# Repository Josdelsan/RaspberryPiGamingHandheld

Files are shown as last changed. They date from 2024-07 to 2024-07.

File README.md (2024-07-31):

# Raspberry Pi Gaming Handheld

This repository contains all the information required in order to build a Raspberry Pi Zero (w/w 2) handheld gaming device. This project was done for educational purposes and it is not intended to be sold or distributed. The guides provided covers one or multiple solutions for each part of the device (Display, Power, Audio, Controls, etc.), the user is free to choose the one that fits their needs better. If you have any issues or you want to showcase your build, feel free to open an issue.

This project was especially designed for fitting a Raspberry Pi Zero inside a GameBoy Advance shell. The GameBoy Advance/GameBoy Color are great options for this project because they are cheap and easy to find. You can adapt the project to fit any other form factor you want.

gba_v1_tloz_2
*GBA based Raspberry Pi Zero 2 W handheld front view*

## Disclaimer

This project requires soldering skills and comprehensive knowledge abour RPI software and hardware. It is not recommended for beginners. Even if the parts cost are low, it may be more expensive than just buying an emulator handheld device like the [Miyoo Mini Plus](https://www.miyoogame.com/product/miyoo-mini-plus-retro-handheld-game-console/) or the [Anbernic RG35XXSP](https://anbernic.com/products/rg35xxsp).

When emulating games, please make sure you own the original copy of the game. This project does not provide any ROMs or information on how to obtain them. All the trademarks and copyrights are property of their respective owners.

## Photos

gba_v1_top
*GBA based Raspberry Pi Zero 2 W handheld top view*

gba_v1_open_back
*GBA based Raspberry Pi Zero 2 W handheld removed back shell*

gba_v1_open_2
*GBA based Raspberry Pi Zero 2 W handheld disassembled*

gba_v0_on
*First iteration of GBA based Raspberry Pi Zero W handheld gaming deviced without shell*

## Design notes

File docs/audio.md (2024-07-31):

# Audio

Audio is an important part of the gaming experience. In this section we will cover an audio solution for the Raspberry Pi Zero W. This solution is based on the I2S capabilities of the Raspberry Pi Zero. You can check the Raspberry Pi PCM pins [here](https://pinout.xyz/pinout/pcm).

**IMPORTANT**, this solution is not currently working for the Raspberry Pi Zero W 2, I am looking for a solution since it works perfectly for the Raspberry Pi Zero W.

## MAX98357A

The MAX98357A is a small I2S amplifier that can be used to output audio from the Raspberry Pi Zero. Adafruit sells it for a few dollars and has an [amazing tutorial](https://learn.adafruit.com/adafruit-max98357-i2s-class-d-mono-amp/raspberry-pi-wiring) on how to use it (wiring and software configuration). The full documentation of Adafruit MAX98357A can be found [here](https://cdn-learn.adafruit.com/downloads/pdf/adafruit-max98357-i2s-class-d-mono-amp.pdf). You can check in the documentation the supported speakers.

If the `dtoverlay=max98357a` provided by Adafruit is not working for you, you can try the following configuration:

```bash
dtoverlay=hifiberry-dac
dtoverlay=i2s-mmap
```

## Dealing with `VolumeControl::init() - Failed to find mixer elements` error

If you have RetroPie installed in your Raspberry Pi Zero, you might encounter the following error when booting games:

```bash
VolumeControl::init() - Failed to find mixer elements
```

This error will affect Raspberry Pi Zero W 2 users that tried to configure the audio and commented out the `dtparam=audio=on` line in the `/boot/config.txt` file. If you try to change audio configurations in the `raspi-config` tool, you will get the error that there is no audio device detected. This error does not affect gameplay, you can play without audio.

If you are going to play without audio, uncomment the `dtparam=audio=on` line in the `/boot/config.txt` file and select HDMI as the audio output in the `raspi-config` tool. This will likely fix the error and you will be able to play without audio. This [post in RetroPie](https://retropie.org.uk/forum/topic/26628/audio-issues-after-latest-raspbian-updates-june-2020) forum goes deeper into this issue.

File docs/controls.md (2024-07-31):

# Controls

## Hardware

For creating a gaming handheld device and avoid using an external controller, we need to add some buttons to the Raspberry Pi. Using internal pull-up/pull-down resistors, we can connect switch buttons directly to the GPIO pins of the Raspberry Pi. Check the Raspberry Pi Zero pinout [here](https://pinout.xyz/).

The tricky part is to add buttons in a way it fits the case you are using and it is comfortable to play. In this section we will cover a few options for adding buttons to the Raspberry Pi Zero. Some of the options are more complex and professional (custom PCBs) and others are more simple and DIY (protoboard).

### Buying a DIY Button PCB Board

One of the easiest and cheapest ways to add buttons to the project is to buy a DIY button PCB board for your specific case. They can be easily found on websites like AliExpress or eBay for the GBA/GB/GBC cases. This PCB will perfectly fit the case (screw holes, case holes, PCB thickness) and will be compatible with the original conductive silicone rubber pads that usually come with the case.



*DIY PCB bought online*

They are not very well documented. You will need to use a multimeter to check which pins are conected to each button and ground. You can directly solder each button to the Raspberry Pi GPIO pins and ground to any GND pin. Sometimes they will include a footprint for a resistor and a smd LED (power LED) that you can omit. This option will give you the most professional look and feel while keeping the cost low.

### DIY Protoboard

If you have some protoboards laying around and you are confident about your soldering/cutting skills, you can create your own DIY button board out of it. This options gives you the flexibility of adding more buttons, changing the layout or using different kind of buttons apart from the conductive silicone rubber pads.

You can use the original conductive silicone rubber pads by creating traces using conductive paint, copper tape or applying solder to the protoboard. In replacement of the conductive silicone rubber pads, you can use push buttons, theses are harder to fit inside the case due to their size and height. Becareful about the protoboard thickness, it might not fit the case.

This method requires more time and effort. It is recommended for people that are looking for the ultimate DIY experience. Please, make sure you have the right tools and knowledge before using cutting tools, soldering irons and other dangerous tools.

### Custom PCB

If you are looking for a professional look and feel, you can design your own custom PCB to fit not only the control but also all the other components of the project (more covered in the custom pcb section). This method can be expensive due to manufacturing, shipping and customs inspection costs (depending on your country). If you are already familiar with PCB design, there is not much to say here. This project PCB design was done using KiCad 8.0.

If you are planning to use push or smd buttons, you will need to look for the footprint or design it using the datasheet of the button. Creating the footprint for the conductive silicone rubber pads is easy. I recommend using a photo at 1:1 of the original gaming console PCB for reference. In this project particular case, the buttons footprint was designed to be compatible with the original conductive silicone rubber pads and also some specific smd buttons.



*Custom PCB version 0.1 made for the GBA based handheld (front)*



*Custom PCB version 0.1 made for the GBA based handheld (back)*

### Different Button Types talk

Choosing the right button type is a very personal decision. Some people stick to the silicone rubber feel (GBA/GB/GBC) while others prefer a more mechanical/clikey feel (GBA sp). After using many different form factor button, here are my thoughts and recommendations:

- **Conductive Silicone Rubber Pads**: They are heavily dependent on the preassure you apply between the board and the shell, it might affect the button feel and response. If you have detection issues you can try sticking small cutouts of copper tape to the pads to increase thickness and conductivity. They will fit perfectly inside its case and plastic buttons, they are silent and cheap.
- **Push Buttons**: They have a more consistent feel and response. Becareful with the operating force, you might feel uncomfortable playing games that requires fast button presses. They are really difficult to fit inside the case due to their size and can be noisy. The case plastic buttons might not fit the push buttons, you will need to 3D print custom ones or modify the existing ones (cutting, sanding, adding silicone glue).
- **SMD Buttons**: They will likely require a custom PCB. Due to its size, you can still use the silicone rubber pads to fit the plastic buttons while using the smd buttons underneath. I heavily recommend looking for really low operating force buttons (like the ones used in the GBA SP) to avoid fatigue while playing.



*Different buttons that are viable*



*Rubber silicone pads*

### [Tutorial] Connecting a Button to the Raspberry Pi

In this tutorial we will connect a simple push button to the Raspberry Pi GPIO pins. This is the most basic way to add buttons to the Raspberry Pi. You can use this tutorial as a base for more complex button configurations.

Button will have two ends, one will be connected to the GPIO pin and the other to the GND pin. When the button is pressed, the GPIO pin will be connected to the GND pin and the Raspberry Pi will detect it as a button press.

If you want to check if the button was correctly connected, you can use `gpiozero` python library. In [its documentation](https://gpiozero.readthedocs.io/en/stable/recipes.html#button) you can find a lot of examples with images and code.

## Software

Buttons can be configured using the `gpiozero` python library. This library provides a simple interface for controlling GPIO devices connected to a Raspberry Pi. This allows creating custom buttons shortcuts for specific actions like system shutdown, etc.

In this particular project, since we are using RetroPie, we will use a Python based GPIO Controller called GPIOnext. It provides a CLI for configuring a gamepad using GPIO pins. You can find more information about it in the [GPIOnext official repository](https://github.com/mholgatem/GPIOnext). This is the easiest way to configure a gamepad in RetroPie using GPIO pins.

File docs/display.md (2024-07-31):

# Display

## Hardware options

There are many display options available for RPI. In this project it was chosen to use an SPI TFT LCD display that uses the ILI9341 driver (not ILI9341V). When using a GameBoy Advance shell, both 2.8 and 3.2 inches will fit. The 3.2 inch may require some modifications to the plastic cover that hold the leds under the screen and aditional software configuration in order to adjust screen borders. These screen usually works at a resolution of 320x240 pixels. They are sold in different formats: presoldered to a pcb, 18 pins connector or 40 pins connector.



*ILI9341 displays (red pcb and 18p) and ILI9341V display (black pcb)*

### ILI9341 display presoldered to a pcb

When searching for ILI9341 display online, it is common to find these displays already soldered to a breakout board. This option is the most soldering friendly and easiest to debug but it may not fit inside the desired shell. When looking for a good fitting display, make sure the display is as centered as possible (display ribbon cable in the opposite side of the pins).



*Displays that are sold with a breakout board*

For this project, touch screen is not used. When buying a display, look for displays that do not have exposed touch screen pins, this will save you space (same for sd card slots). You could ultimately remove the pins if you are not going to use them and/or modify the pcb using a cutting tool. Be extremely careful when modifying any pcb since it is very easy to damage the display and make it unusable (**NOT RECOMMENDED**).

When using theses displays, make sure to check the voltage required to power. They usually work at 3.3V or 5V. They are packed with different pins configurations, it is important to check the pins for later driver software configuration. Some manufacturers will replace SDI (MISO) and SDO (MOSI) for a single SDA that works as SDI. For this purpose, only SDI is used.

### ILI9341 18 pins connector display

ILI9341 with 18 pins ribbon connector are usually cheaper than the presoldered displays and easier to fit inside the shell. The downside is that they require precise soldering skills and some kind of breakout board in order to connect it to the RPI. A custom pcb is presented in the custom pcb section for this purpose.



*18 pin connector ILI9341 display*

The 18 pins connector are configured as follows (make sure to check the datasheet of the display you are using):
- GND
- RESET
- SCL/CLK (Clock)
- DC (Data control)
- CS (Chip select)
- SDI/SDA (MISO) (Standard input)
- SDO (MOSI) (Standard output)
- GND
- VCC (3.3V)
- LEDA (Backlight LED Anode)
- LEDK1 (Backlight LED Cathode)
- LEDK2 (Backlight LED Cathode)
- LEDK3 (Backlight LED Cathode)
- LEDK4 (Backlight LED Cathode)
- XL (Touch screen)
- YU (Touch screen)
- XR (Touch screen)
- YD (Touch screen)

You will need to connect a resistor between 3.3v and LEDA in order to power the backlight. The value of the resistor will depend on how much brightness you want to achieve. I find 10R to be a good value for my needs. It could also be powered by a PWN pin in order to control the brightness, RPI0 has support for software PWM, It is not recommended for gaming sessions since it may cause flickering.

### ILI9341 40 pins connector display

ILI9341 with 40 pins connector are similar priced to the 18 pins connector and harder to work with. I have not tested any of these displays and I discourage their use against the 18 pins version for these kind of projects.

### Other displays

This project was heavily based on the [fbcp-ili9341 driver](https://github.com/juj/fbcp-ili9341), so it is recommended to use an 4-wire SPI display that is supported by this driver. If you use an alternative display in your project that requires additional information, feel free to contribute to this guide.

### [Tutorial] Connecting an SPI display

Raspberry Pi has two Serial Peripheral Interface (SPI) buses, SPI0 and SPI1. SPI1 is disabled by default, so we will be using SPI0 for the screen connection. SPI0 pins are 19, 21, 23, 24 and 26 (GPIO 7, 8, 9, 10 and 11). The display will be connected as follows:

- GND -> GND
- VCC -> 3.3V or 5V depending on the display
- CS -> GPIO 8 (SPI0 CE0)
- RESET -> GPIO 25
- DC -> GPIO 24
- CLK -> GPIO 11 (SPI0 SCLK)
- SDI -> GPIO 10 (SPI0 MOSI)
- SDO -> GPIO 9 (SPI0 MISO)
- LED -> 3.3V or 5V depending on the display

RESET and DC pins can be connected to any GPIO pin, it is important to remember the pin number for later software configuration. Some displays may have different pin names/configurations, make sure to check the datasheet of the display you are using. The essential pins for 4 wire SPI are CS, RESET, DC, CLK, SDI(SDA). Some breakout boards may not have LED/BLK pins since they use the VCC pin to power the backlight. You can check RPI pinout [here](https://pinout.xyz/pinout/spi).

## Software configuration for SPI displays

The software use for configuring the display may vary depending on the OS version. In this guide, we will cover two options `fbcp-ili9341` (up to Debian 10 buster) and `panel-mipi-dbi` (from Debian 11 bullseye). When installing Retropie (4.8) from Raspberry Pi imager, it will install Debian 10 (22/07/2024). It is recommended to use this version so the display is configured using `fbcp-ili9341`.

**DISCLAIMER** We will explain how to configure `panel-mipi-dbi` eventhough its performance is not good when running emulationstation because it forces software (CPU) rendering. Feel free to contribute to this guide if you find a solution.

### [Tutorial] Configuring fbcp-ili9341

You may need some dependencies in order to clone and build the driver like `cmake` and `git`. This tutorial will cover basic driver installation, check [driver GitHub repository](https://github.com/juj/fbcp-ili9341) for more detailed information.

1. Make sure you have a valid OS version (Debian 10 buster or older) in order to use `fbcp-ili9341`. You can check your OS version by running the command `lsb_release -a`.

2. Clone the repository to your desired location (I will use `/home/pi` for this guide):
```bash
git clone https://github.com/juj/fbcp-ili9341.git
```

3. Enter the repository folder and create a build folder:
```bash
cd fbcp-ili9341
sudo mkdir build
cd build
```

4. Run cmake to generate the makefile, this command is configured to use an ILI9341 display with RESET and DC pins connected to GPIO 25 and 24 respectively. display statistics are turned off and clock divisor is set to 6 (30 is a good starting point for debugging). Check fbcp-ili9341 repository for more information on how to configure the driver for other displays and additional options.
```bash
sudo cmake -DILI9341=ON -DGPIO_TFT_DATA_CONTROL=24 -DGPIO_TFT_RESET_PIN=25 -DSPI_BUS_CLOCK_DIVISOR=6 -DSTATISTICS=0 ..  
```

5. Build the driver:
```bash
sudo make -j
```

6. Modify the `/boot/config.txt` file to configure the display. Make sure the following lines are added or uncommented. Check `hdmi_cvt` values for your display resolution. The following configuration is for a 320x240 display.
```bash
hdmi_force_hotplug=1
disable_overscan=1
hdmi_cvt=320 240 60 5
hdmi_group=2
hdmi_mode=87
hdmi_drive=2
```

7. Comment the following lines in `/boot/config.txt`:
```bash
#dtparam=spi=on
```

8. Run the driver. There are two options, `systemd` service or `rc.local` script. Both options work fine, but system service is a bit faster and easier to debud using `systemctl` command.

- Configure `rc.local` script. Modify the file `/etc/rc.local` and add the following line before `exit 0`:
```bash
/home/pi/fbcp-ili9341/build/fbcp-ili9341 &
```

- Configure `systemd` service. Create a service (named `display.service` in this example) file in `/etc/systemd/system/` with the following content:
```bash
[Unit]
Description=Display driver
Before=basic.target
After=local-fs.target sysinit.target
DefaultDependencies=no

[Service]
Type=simple
ExecStart=sudo /home/pi/fbcp-ili9341/build/fbcp-ili9341 &

[Install]
WantedBy=basic.target
```

9. In case you are using `systemd` service, enable and start the service:
```bash
sudo systemctl enable display.service
sudo systemctl start display.service
```

10. Reboot the system and the display should be working. If you have any issues, check the driver output using `systemctl status display.service` (if using systemd).

### [Tutorial WIP] Configuring panel-mipi-dbi
panel-mipi-dbi driver documentation can be found [here](https://github.com/notro/panel-mipi-dbi/wiki). This driver is used in Debian 11 bullseye and newer versions. I tested this method with Debian desktop version and headless version, both worked fine but there is a performance issue when running emulationstation (seems like it forces software rendering). Feel free to contribute to this guide if you find a solution.

1. Add the following lines to `/boot/config.txt`. Make sure to change the resolution values to match your display resolution and the GPIO pins for RESET and DC pins.
```bash
dtoverlay=mipi-dbi-spi,speed=32000000
dtparam=compatible=ili9341\0panel-mipi-dbi-spi
dtparam=width=320,height=240,width-mm=57,height-mm=43
dtparam=reset-gpio=25,dc-gpio=24
```

2. Create a txt file for the display firmware commands. The following commands are for ILI9341 displays. Make sure to check the datasheet of the display you are using. Save the following content to a txt file:
```bash
command 0x28
command 0xcf 0x00 0xc1 0x30
command 0xed 0x64 0x03 0x12 0x81
command 0xe8 0x85 0x00 0x79
command 0xcb 0x39 0x2c 0x00 0x34 0x02
command 0xf7 0x20
command 0xea 0x00 0x00
command 0xc0 0x1d
command 0xc1 0x12
command 0xc5 0x33 0x3f
command 0xc7 0x92
command 0x3a 0x55
command 0xb1 0x00 0x12
command 0xb6 0x0a 0xa2
command 0x44 0x02
command 0xf2 0x00
command 0x26 0x01
command 0xe0 0x0f 0x2a 0x28 0x08 0x0e 0x08 0x54 0xa9 0x43 0x0a 0x0f 0x00 0x00 0x00 0x00
command 0xe1 0x00 0x15 0x17 0x07 0x11 0x06 0x2b 0x56 0x3c 0x05 0x10 0x0f 0x3f 0x3f 0x0f

command 0x2A 0x00 0x00 0x00 0xEF
command 0x2B 0x00 0x00 0x01 0x3F
command 0x2C

command 0x11
delay 100
command 0x21
command 0x29
delay 100
command 0x36 0x28
```

Commands for ILI9341 and ILI9341V are almost the same, it is only necessary to change display orientation (mirror image) and RGB order.
- [ILI9341 datasheet](https://cdn-shop.adafruit.com/datasheets/ILI9341.pdf)
- [ILI9341V datasheet](https://www.displayfuture.com/Display/datasheet/controller/ILI9341V.pdf)

3. Use the script provided by panel-mipi-dbi repository to create a firmware file. It can be found [here](https://github.com/notro/panel-mipi-dbi). Use the script and name the output file a `ili9341.bin`:
```bash
mipi-dbi-cmd ili9341.txt ili9341.bin
```

4. Copy the firmware file to `/lib/firmware/`. If you binary file is named differently, modify the `dtparam=compatible=ili9341\0panel-mipi-dbi-spi` to match `dtparam=compatible=yourfilename\0panel-mipi-dbi-spi`.
```bash
sudo cp ili9341.bin /lib/firmware/
```

5. Reboot the system and the display should be working.

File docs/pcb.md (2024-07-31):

# Custom PCB

This section will cover some of the design decisions made for the custom GBA like PCB that is shared in this repository. This was my first PCB design ever, I decided to got for a custom PCB because when I built the first prototype I got pretty tired of dealing with a bunch of wires and soldering. I wanted to have a more professional finish and an easier way to fit the screen, buttons and other components. The PCB does not use any components apart from the modules (audio, power), Raspberry Pi Zero, the screen, USB port and power switch (resistor and power LED are optional). The goal was to simplify the wiring process and keeping the PCB cost as low as possible.

## Using the shared PCB

The PCB shared in this repository is the second version of the original PCB that I first designed. I corrected some design flaws related to the component placement that made the display fit so tight that causes some light inconsistencies in the screen.

If you are going to use this PCB, edit it or create your own, I recommend be careful with the PCB thickness. 1.6mm is commonly the cheapest option but it does not fit the GBA case for a few millimeters. I had to sand the shell a little bit to be able to close it. It really depends on the mechanical strength you need for your case.

I have not tested the PiBA v0.2 version but It should work exactly the same as the v0.1. I will update this section when I test it. Take into account that I am not a PCB designer, this design can be heavily improved.

## Board components

The following list contains the components used in the PCB, some of them are optional.

- **Raspberry Pi Zero W (W 2)**: It is mean to be soldered in the back of the PCB with the CPU facing to the back. You could flip the footprint if you want to solder some female 2-20P pin peader socket connector and use a RPI0 that came with the pin header pre-soldered (be careful with the height of the pin header in that case).
- **MH-CD42**: Power module that provides 5V output and charging circuit for lithium batteries.
- **6pin USB C port**: USB C port for power input.
- **R2 and R3**: Optional 5k1 resistor connected to USB C cc line for USB C to USB C cables.
- **JST 2.0 PH 2-pin connector**: Battery connector, any other connector could be used if needed.
- **Power switch**: GBA power switch.
- **ILI9341**: 2.8" or 3.2" TFT display. The 18pin version is meant to be soldered to the spare PCB part that can be cutted off. Any other display can be soldered to the 9 pins.
- **MAX98357**: Optional audio amplifier.
- **5 pin potentiometer**: Optional volume control.
- **Speaker**: Optional speaker.
- **Power LED**: Optional power LED.
- **R4**: Resistor for power LED.
- **RB, RL and AUX buttons**: Momentary tactile tact push buttons 4-Pin right angle (6x6mm, height does not matter but more than 5mm is recommended). The AUX button is optional, it takes the place of the original GBA headphone jack and it is meant to be used as a hotkey button.

## Adjust the PCB layout in KiCad to fit any case

The PCB cutout is designed to fit the GBA case but it can be easily adjusted to any other case. If you want to adapt to any other case, I recommend you find a 3D model of the case or a nice original case pcb scan. You can use an 1:1 image in KiCad to adjust the PCB layout to the case.

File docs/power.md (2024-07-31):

# Power

Powering the Rapsberry Pi Zero can be achieved using the micro USB port that comes with the board. For obvious reasons, this is not a viable option for a handheld gaming device. The most straightforward way to power the RPI0 is connecting a battery to one of the 5V pins and GND pins.

## Batteries

There are a few options for batteries, we will comment on the most common ones.

### 3.7V Lithium Battery

It is the most common choice when it comes to powering small electronics. They usually comes with a JST 2.0 PH 2-pin connector that makes it easy to connect/disconnect. The capacity of the battery will depend on the size of the device and the power consumption of the components. For this project, a 2000mAh battery should be enough to power the RPI0 and the display for a few hours.

I have tested a 103450 2000mAh battery and it has been working perfectly when it comes to battery life. A bit of case modding is required to fit the battery inside the GBA shell.



*3.7V Battery*

### AA Batteries

AA or other form factor batteries can be a nice choice if the case has already a battery compartment. You will have to check whether they are connected in series or parallel and the voltage they provide in order to correctly regulate it to 5V.

I find this method a bit more complicated and less convenient (specially non-rechargeable batteries). It is a good choice if you are looking for a more nostalgic experience.

## Power modules

In order to power the RPI0, we need a module responsible for regulating the voltage and safely charging the battery. All the information provided here is based on testing with 3.7V lithium batteries.

**IMPORTANT**, make sure you know what you are doing when manipulating batteries. They can be dangerous if not handled correctly. Take this information as a guide and not as a step-by-step tutorial. Always double check the information provided here with other sources.

### MH-CD42

The MH-CD42 is a small all-in-one module that provides a 5V output and a charging circuit for lithium batteries. It is very easy to use and it is perfect for this project. It can be found on AliExpress for a few dollars.

It includes lithium battery protection, overcurrent protection, overvoltage protection, short circuit protection, over temperature protection and 4 LEDs for battery level indication. It also has a KEY pin/button that can be used to turn on/off the output.

The output is 5V but it lacks of USB port. You will have to buy an USB (C or micro) connector and solder it to the output pins.



*MH-CD42 power module*

### TP4056

The TP4056 is similar to the MH-CD42 but it lacks the voltage regulation so you will have to use a step-up converter to get the 5V output. It has an integrated USB port (USB spec depends on the model). If you are buying the USB C version, make sure it is configured to work with USB C to USB C cables (resistor connected to CC pin).

I have seen many different versions of this module even if they are all called TP4056. Make sure to check the datasheet of the module you are buying.



*TP4056 power module*

## Power button

Adding a power button to the project is necessary if we want to turn on/off the device without having to disconnect the battery. It can be as simple as a switch that connects the battery to the power module or as complex as a button that sends a signal to a microcontroller than safely turns off the Raspberry Pi. There are a few ideas for adding a power button to the project:

### Simple switch

Using a simple switch to connect the battery to the power module is the easiest way to add a power button. Make sure the switch can handle the current draw of the RPI otherwise it will be stuck in a boot loop.

It is also a nice choice when using a console shell since you can use the original power switch and achieve a more professional look. For the GBA shell, you can find an original power switch that fits the case online.

This method will not allow the Raspberry Pi to safely shutdown. This might end up corrupting the SD card if the device is turned off while writing data (It has never happened to me but it is a possibility). It is recommended to creating a button shortcut/gpio-shutdown dtoverlay that triggers a safe shutdown before turning off the power or use emulationstation shutdown option.

The script for safely shutting down pressing multiple buttons can be done using Python and `gpiozero` library. Simple example:

```python
# Shutdown rpi zero
import time
import os
from gpiozero import Button

def shutdown(channel=None):
    os.system("sudo shutdown -h now")

b1 = Button(7)
b2 = Button(13)
b3 = Button(12)

while True:
    if b1.is_pressed and b2.is_pressed and b3.is_pressed:
        shutdown()
    time.sleep(0.5)
```

### Using MH-CD42 KEY pin

The MH-CD42 module exposes a button pin that can be used to turn on/off the output. Connect one push button terminal to the KEY pin and the other to GND. A single press will turn on the output and a long press will turn off the output.

This method is a nice way to control the power but it lacks the ability to prevent the device turning on when the battery is being charged. Additionally, if you still have room for push buttons next to the power button, you can add a safe shutdown button using the same method as the previous example or configuring a dtoverlay in the `/boot/config.txt` file. More information about gpio-shutdown can be found [here](https://github.com/raspberrypi/firmware/blob/master/boot/overlays/README#L1643).

### Using a microcontroller

For a more professional finish, a microcontroller can be used to read the power switch state and safely shutdown the Raspberry Pi before cutting the power. Using dtoverlays, a GPIO pin can be configured to be set to low when the Raspberry Pi is shutting down. This pin can be connected to the microcontroller to indicate the shutdown state and cut the power when the Raspberry Pi is off.

This option may be overkill given the previous options but it is a nice way to learn about microcontrollers and how to communicate with the Raspberry Pi. Becareful about microcontroller power consumption and size, it might not fit inside the case.

## USB ports

Adding an USB charging port to the project is the most convenient way to charge the battery. It is up to you to decide whether you want to use a micro USB, USB C, mini USB or any other form factor. Make sure to read the datasheet of socket you are buying in order to correctly connect the pins.

If you are using an USB C port, take into account that some of presoldered USB C ports to PCBs lacks the CC pin resistors so you cannot use USB C to USB C cables. If you are gonna buy a USB C port and solder it yourself, I recommend buying the 6-pin version for easier soldering and adding the resistors yourself (5.1k for CC1 and 5.1k for CC2, both to GND).

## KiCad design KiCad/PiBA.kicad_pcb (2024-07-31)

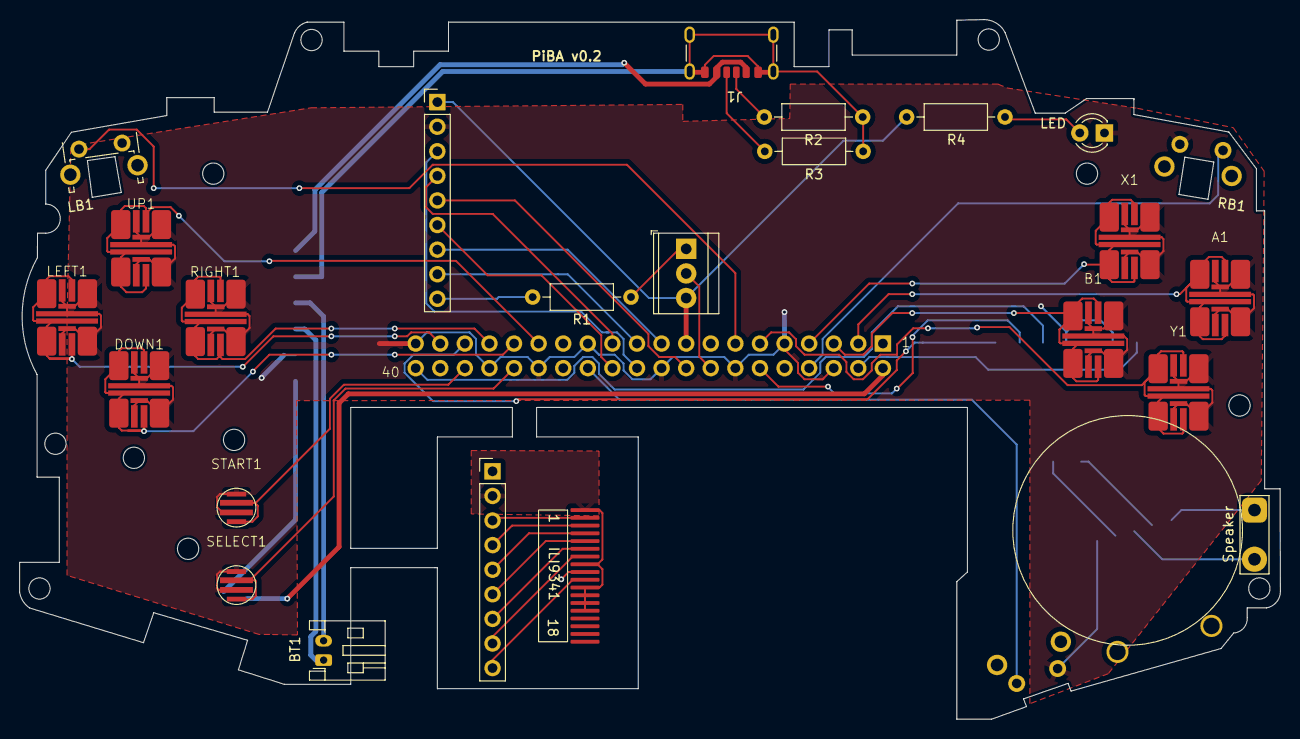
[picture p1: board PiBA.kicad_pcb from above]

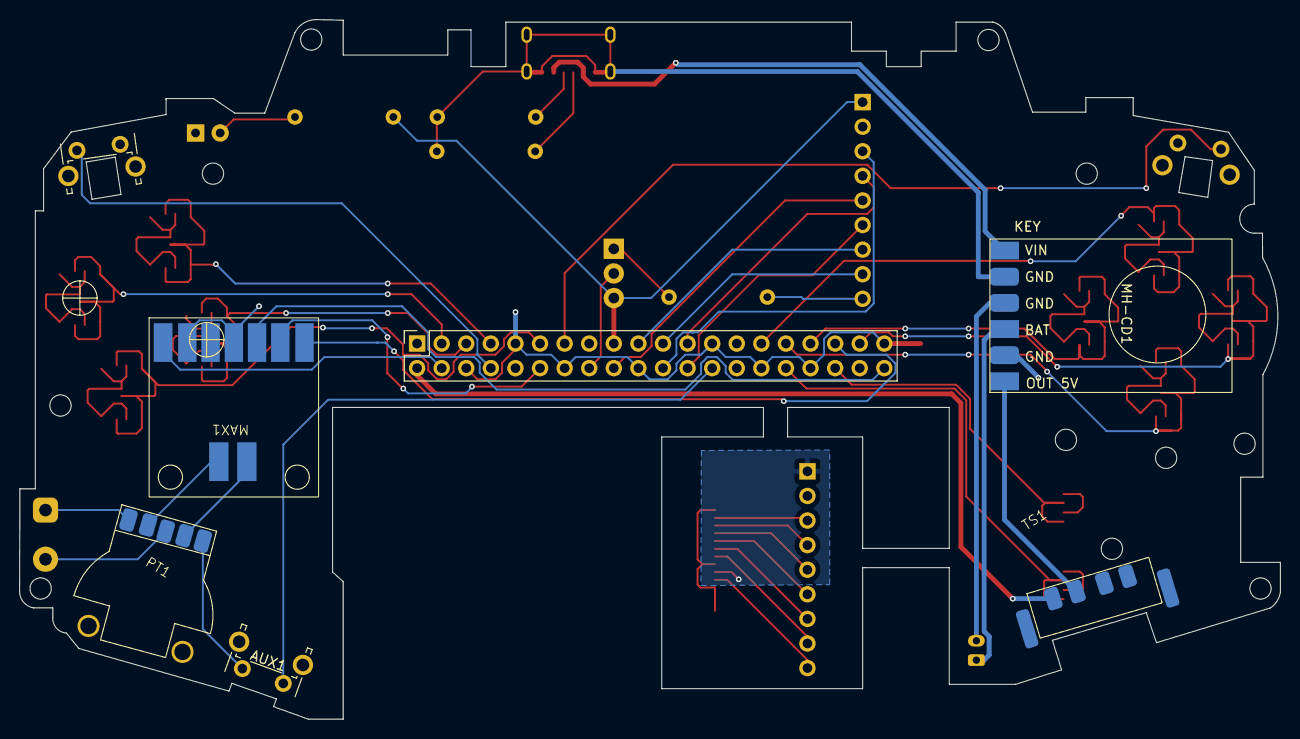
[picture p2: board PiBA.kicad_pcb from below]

Board: 2 copper layers, 130.2 x 72.3 mm, 30 parts (7 on the bottom side), 50 nets.

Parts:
A1: A; gba_button_switch_pad
AUX1: RB; SW_Tactile_SPST_Angled_PTS645Vx39-2LFS
B1: B; gba_button_switch_pad
BT1: Battery_Cell; JST_PH_S2B-PH-K_1x02_P2.00mm_Horizontal
D1: LED; LED_D3.0mm
DOWN1: DOWN; gba_button_switch_pad
ILI1: ILI9341 solder pad
ILI9341Extension1, ILI9341Extension2: PinHeader_1x09_P2.54mm_Vertical
J1: USB_C_Receptacle_PowerOnly_6P; USB_C_Receptacle_GCT_USB4125-xx-x_6P_TopMnt_Horizontal
J2: Conn_01x03; TerminalBlock_TE_282834-3_1x03_P2.54mm_Horizontal
LB1: LB; SW_Tactile_SPST_Angled_PTS645Vx39-2LFS
LEFT1: LEFT; gba_button_switch_pad
LS1: Speaker; TestPoint_2Pads_Pitch5.08mm_Drill1.3mm
MAX1: MAX98357
MH-CD1: MH-CD42
PT1: Pot b103
R1: 10R; R_Axial_DIN0207_L6.3mm_D2.5mm_P10.16mm_Horizontal
R2, R3: 5k1; R_Axial_DIN0207_L6.3mm_D2.5mm_P10.16mm_Horizontal
R4: 150R; R_Axial_DIN0207_L6.3mm_D2.5mm_P10.16mm_Horizontal
RB1: RB; SW_Tactile_SPST_Angled_PTS645Vx39-2LFS
RIGHT1: RIGHT; gba_button_switch_pad
RaspberryPiZero2W1: RPIZero
SELECT1: SELECT; gba_button_stsl
START1: START; gba_button_stsl
TS1: Toggle switch
UP1: UP; gba_button_switch_pad
X1: X; gba_button_switch_pad
Y1: Y; gba_button_switch_pad

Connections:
+3V3: ILI9341Extension2.1 (VCC), J2.3, R4.1, RaspberryPiZero2W1.17 (3V3)
+5V: MAX1.1 (VIN), RaspberryPiZero2W1.4 (5V)
BAT GND: BT1.2 (-), MH-CD1.4 (GND)
GND: A1.2, AUX1.2, B1.2, D1.1, DOWN1.2, ILI9341Extension2.2 (GND), LB1.2, LEFT1.2, MAX1.2 (GND), MAX1.4 (GAIN), MH-CD1.2 (GND), PT1.1 (GND), RB1.2, RIGHT1.2, RaspberryPiZero2W1.6 (GND), RaspberryPiZero2W1.9 (GND), RaspberryPiZero2W1.14 (GND), RaspberryPiZero2W1.20 (GND), RaspberryPiZero2W1.25 (GND), RaspberryPiZero2W1.30 (GND), RaspberryPiZero2W1.34 (GND), RaspberryPiZero2W1.39 (GND), SELECT1.2, START1.2, UP1.2, X1.2, Y1.2
GPIO2: A1.1, RaspberryPiZero2W1.3 (GPIO2/SDA1)
GPIO3: B1.1, RaspberryPiZero2W1.5 (GPIO3/SCL1)
GPIO4: RaspberryPiZero2W1.7 (GPIO4/GPIO_GCLK), X1.1
GPIO5: RaspberryPiZero2W1.29 (GPIO5), UP1.1
GPIO6: DOWN1.1, RaspberryPiZero2W1.31 (GPIO6)
GPIO7: AUX1.1, RaspberryPiZero2W1.26 (SPI_CE1_N/GPIO7)
GPIO12: RaspberryPiZero2W1.32 (GPIO12), SELECT1.1
GPIO13: RIGHT1.1, RaspberryPiZero2W1.33 (GPIO13)
GPIO14: RB1.1, RaspberryPiZero2W1.8 (TXD0/GPIO14)
GPIO16: RaspberryPiZero2W1.36 (GPIO16), START1.1
GPIO17: RaspberryPiZero2W1.11 (GPIO17/GPIO_GEN0), Y1.1
GPIO18: MAX1.6 (BCLK), RaspberryPiZero2W1.12 (GPIO_GEN1/GPIO18)
GPIO19: MAX1.7 (LRC), RaspberryPiZero2W1.35 (GPIO19)
GPIO21: MAX1.5 (DIN), RaspberryPiZero2W1.40 (GPIO21)
GPIO26: LEFT1.1, RaspberryPiZero2W1.37 (GPIO26)
GPIO27: LB1.1, RaspberryPiZero2W1.13 (GPIO27/GPIO_GEN2)
unnamed: BT1.1 (+), MH-CD1.3 (BAT_3V7)
unnamed: D1.2, R4.2
unnamed: ILI1.9 (3V3), ILI9341Extension1.1 (VCC)
unnamed: ILI1.3 (CLK), ILI9341Extension1.4 (CLK)
unnamed: ILI1.5 (CS), ILI9341Extension1.6 (CS)
unnamed: ILI1.4 (DC), ILI9341Extension1.5 (DC)
unnamed: ILI1.10 (LEDA), ILI9341Extension1.9 (LED)
unnamed: ILI1.1 (GND), ILI1.8 (GND), ILI1.11 (LEDK1), ILI1.12 (LEDK2), ILI1.13 (LEDK3), ILI1.14 (LEDK4), ILI9341Extension1.2 (GND)
unnamed: ILI1.2 (RESET), ILI9341Extension1.3 (RESET)
unnamed: ILI1.6 (SDI/SDA), ILI9341Extension1.7 (SDI)
unnamed: ILI1.7 (SDO), ILI9341Extension1.8 (SDO)
unnamed: ILI9341Extension2.9 (LED), R1.1
unnamed: J1.A5 (CC1), R2.2
unnamed: J1.B5 (CC2), R3.2
unnamed: J2.1, R1.2
unnamed: MAX1.8 (S1), PT1.2 (Ch1_IN)
unnamed: MAX1.9 (S2), PT1.4 (Ch2_IN)
unnamed: J1.A9 (VBUS), J1.B9 (VBUS), MH-CD1.6 (VIN_5V)
unnamed: LS1.1, PT1.5 (Ch1_OUT)
unnamed: LS1.2, PT1.3 (Ch2_OUT)
PIN GND: J1.A12 (GND), J1.B12 (GND), J1.S1 (SHIELD), MH-CD1.5 (GND), R2.1, R3.1
POWER: MH-CD1.1 (OUT_5V), TS1.2
POWERIN: RaspberryPiZero2W1.2 (5V), TS1.1
clk: ILI9341Extension2.4 (CLK), RaspberryPiZero2W1.23 (GPIO11/SPI_SCLK)
cs: ILI9341Extension2.6 (CS), RaspberryPiZero2W1.24 (SPI_CE0_N/GPIO8)
dc: ILI9341Extension2.5 (DC), RaspberryPiZero2W1.18 (GPIO_GEN5/GPIO24)
led: J2.2, RaspberryPiZero2W1.16 (GPIO_GEN4/GPIO23)
reset: ILI9341Extension2.3 (RESET), RaspberryPiZero2W1.22 (GPIO_GEN6/GPIO25)
sdi: ILI9341Extension2.7 (SDI), RaspberryPiZero2W1.19 (GPIO10/SPI_MOSI)
sdo: ILI9341Extension2.8 (SDO), RaspberryPiZero2W1.21 (GPIO9/SPI_MISO)
